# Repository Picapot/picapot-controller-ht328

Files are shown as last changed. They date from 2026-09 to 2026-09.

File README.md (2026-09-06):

# Picapot Irrigation Controller

This repository contains the latest firmware for the Picapot Irrigation Controller HT328.3.2.

The hardware design, user manual, 3D printable enclosure, and complete project documentation are freely available at:

https://www.picapot.com

## Build and Upload

A precompiled `.hex` file is available for direct upload to the microcontroller. If you don't need to change anything of the program, you can just upload the precompiled firmware.

### Compile from Source 

The code has been developed using the Arduino IDE and should be compiled using the GyverCore board package. You can add this board to the Arduino IDE by adding the following line to **Settings → Additional Boards Manager URLs**:

```text
https://alexgyver.github.io/package_GyverCore_index.json
```

**GyverCore board settings**

- B.O.D.: `2.7V [Default]`
- Bootloader: `Without bootloader [Warning!]`
- Clock: `External 16 MHz`
- Clock out: `Disable [Default]`
- Compiler version: `AVR-GCC v5.4 or 7.3 [Default]`
- Save EEPROM: `Enable`
- Initialization: `Enable [Default]`
- Serial: `Default Serial`
- System timer: `Enable [Default]`

### Upload to the Controller

The compiled `.hex` file can be uploaded to the microcontroller via port P1 using an AVR programmer and the [AVRDUDE](https://github.com/avrdudes/avrdude/releases) command-line tool.

The first command sets the correct fuses:

```console
avrdude -c avrispmkii -p atmega328p -B 100 -v -U lfuse:w:0xEF:m -U hfuse:w:0xC7:m -U efuse:w:0xFD:m
```

The second command uploads the program to flash memory:

```console
avrdude -c avrispmkii -p atmega328p -B 0.5 -v -U flash:w:picapot-controller-ht328.ino.hex:i
```

The programmer used in the commands above is the AVR ISP MKII (`avrispmkii`). If you are using a different programmer, update the programmer ID in the commands accordingly.

To run the commands as shown, AVRDUDE must be available in the system `PATH`, and the `.hex` file must be in the terminal's current working directory.

### First Run

During the first execution of the firmware, the controller scans the 1-Wire network to detect the internal DS18B20 temperature sensor and stores its address in EEPROM. **It is important that no external sensors are connected at this stage**; otherwise, the controller will not be able to distinguish between the internal and external sensors.

## Repository Contents

- **picapot-controller-ht328.ino** — Firmware source code
- **picapot-controller-ht328.ino.hex** — Precompiled firmware for 128×64 SPI OLED displays based on SSD1306 and SSD1309 controllers

## Dependencies

- **Wire (I²C)**  
  https://github.com/esp8266/Arduino/blob/master/libraries/Wire/Wire.h

- **OneWire**  
  https://github.com/PaulStoffregen/OneWire

- **Dusk2Dawn**  
  https://github.com/Picapot/Dusk2Dawn  
  (fork of https://github.com/dmkishi/Dusk2Dawn)

- **SSD1306Ascii**  
  https://github.com/Picapot/SSD1306Ascii  
  (fork of https://github.com/greiman/SSD1306Ascii)

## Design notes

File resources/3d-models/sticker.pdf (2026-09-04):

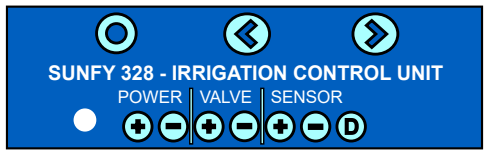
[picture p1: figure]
SUNFY 328 - IRRIGATION CONTROL UNIT; POWER; VALVE; SENSOR

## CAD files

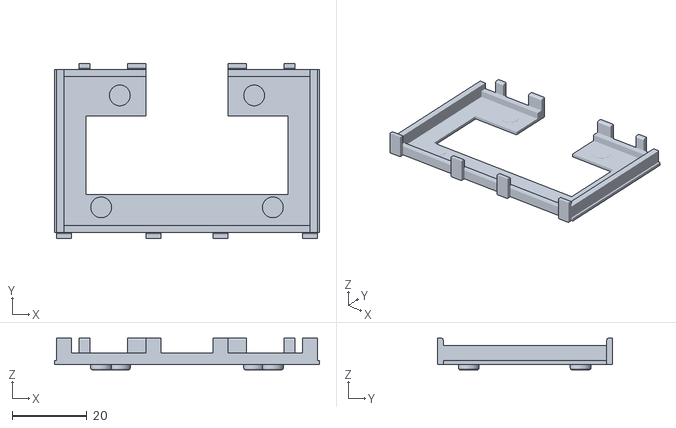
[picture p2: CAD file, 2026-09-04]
resources/3d-models/controller_screen_spacer.stl
71.0 x 46.8 x 8.50

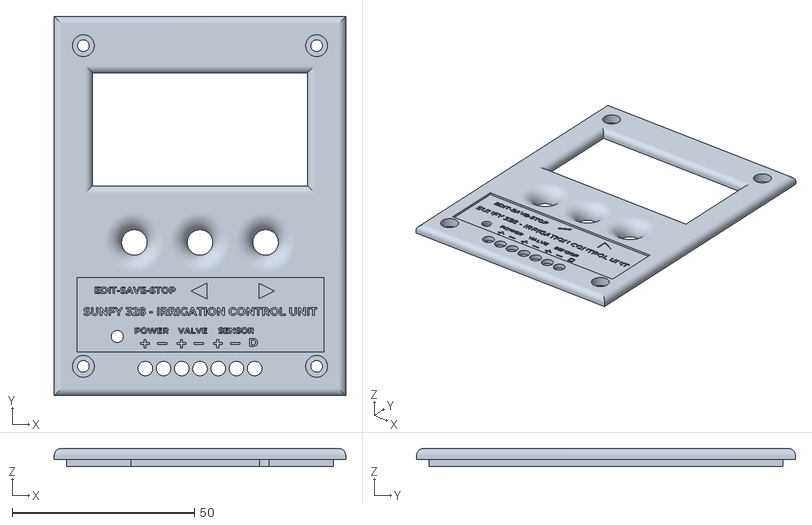
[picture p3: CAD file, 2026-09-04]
resources/3d-models/Picapot328-Cover.stl
80.0 x 104.0 x 5.00

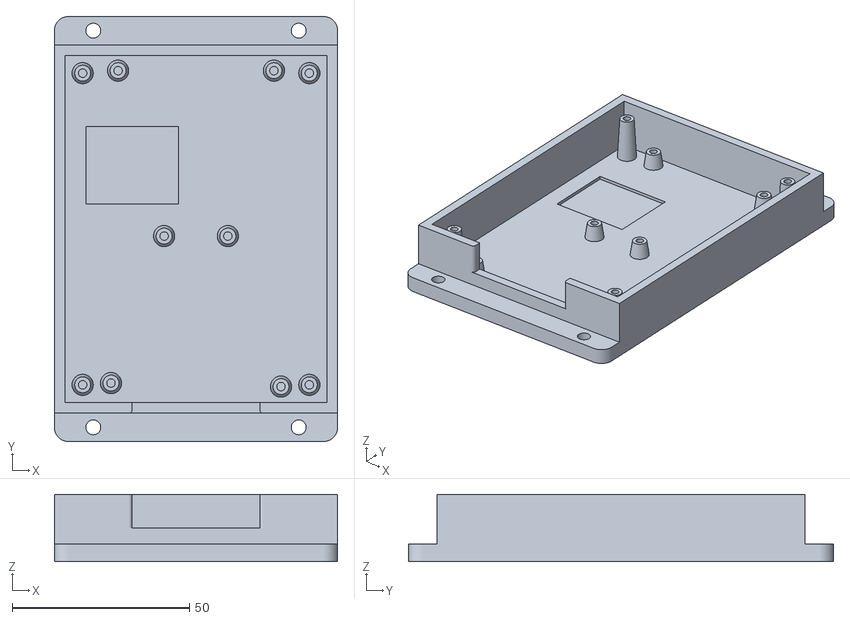
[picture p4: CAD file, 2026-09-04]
resources/3d-models/Picapot328-Base.stl
80.0 x 120.0 x 19.0

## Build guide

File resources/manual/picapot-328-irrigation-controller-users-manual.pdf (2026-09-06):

# Picapot 328 - Irrigation Controller

# User’s Manual

Version 3.2 rev. 5 Sep 2026

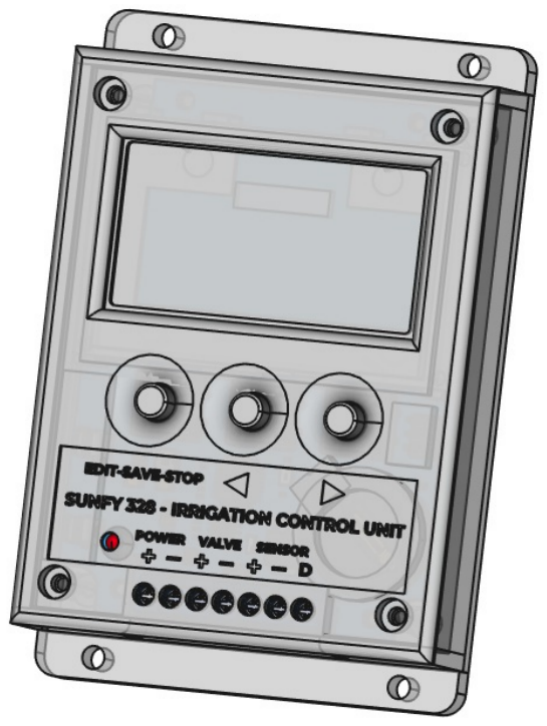
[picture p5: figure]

# Features

Picapot 328 can control one 12 V DC load (such as a solenoid valve, water pump, or relay) with a maximum continuous power consumption of 30 W. Real-time clock with optional automatic daylight saving, geolocation-based sunrise/sunset, fractional timezone support, leap year handling, calibration, and CR2032 battery backup.
Four watering modes: Fixed time, sunrise/sunset-automatic, sunrise/sunset-advanced, and fixed interval. Base duration can range from 15 seconds to 1 hour; seasonal compensation and Heat Boost can extend automatic watering.
Optional automatic seasonal adjustment of duration and watering interval.¹
Boost watering during heatwaves.
Frost protection: skip watering when the temperature is below 5 degrees to safeguard plants and the valve.
Manual watering with a timer for immediate valve control.
Skip watering based on soil moisture (requires an external soil moisture sensor).
Event history for the six most recent automatic waterings, manual waterings, and skipped waterings.
Automatic fallback to the internal temperature sensor if the selected external sensor is unavailable.
Low power consumption, ideal for off-grid systems.

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
# Installation

The control unit is not waterproof and must be enclosed in a waterproof box if installed outdoors.

The connector block has seven terminals. Connect them as described below.

Important - first start: power up the controller for the first time with only the internal DS18B20 connected. The controller stores the first detected sensor as the internal sensor. Connect the external sensor only after this initial registration has completed.

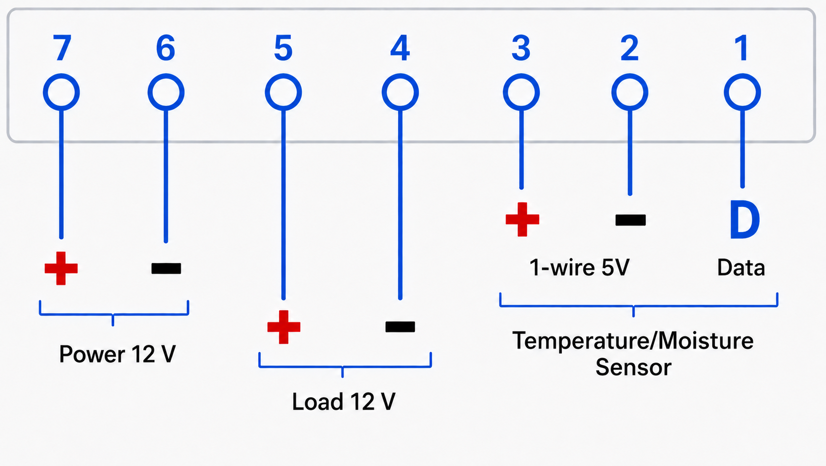
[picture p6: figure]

Picapot 328 terminal layout

Terminal | Description
7, 6 | Connect these two terminals to a 12 V power source. The power source must provide at least 0.25 A to supply the control unit and the sensor, in addition to the load current. The total current drawn by the system is limited by a 3 A fuse. The unit is protected against reverse polarity. 7) Positive (+12 V) 6) Negative
5, 4 | Connect these two terminals to the load, which must operate at the same voltage as the power source. Irrigation systems typically use a solenoid valve and/or a water pump. Solenoid valves are not polarity-sensitive, so the wires can be connected either way. Water pumps, however, must be connected with the correct polarity. The maximum continuous load power is 30 W at 12 V DC. Motor starting currents must also be considered. For higher-power loads, use an external relay rated for the load and its starting current, driven by the Picapot controller. 5) Positive (+12 V) 4) Negative

Picapot 328 - User's Manual - Version 3.2 rev. 5 Sep 2026 - www.picapot.com

Terminal | Description
3, 2, 1 | Connect these three terminals to the optional external sensor. The sensor can be a DS18B20, which provides temperature, or the Picapot PS100, which provides both temperature and soil moisture. The controller supports one internal sensor and one external sensor. 3) Positive (+5 V) 2) Negative 1) Data line

# Operation

The controller provides seven screens.

No. | Screen | Modes | Description
1 | Date/Time | View/Edit | The main screen shows the date, time, and sensor data.
2 | Schedule | View/Edit | Configuration of the waterings.
3 | Location | View/Edit | Unit geolocation, timezone, and daylight saving.
4 | Options | View/Edit | Remaining controller options.
5 | Events | View | History of automatic, manual, and skipped watering events.
6 | Sensor | View | Minimum and maximum temperatures and moisture levels of the day.
7 | Manual | View/Edit | Immediate watering.

Screens can be managed using three buttons:

Button | Position | Functions
1 | Left | Enter/exit edit mode when pressed for more than 2 seconds. In edit mode, move to the next edit cell. Stop watering when pressed for more than 2 seconds from the Date/Time screen.
2 | Middle | In view mode, move to the previous screen. In edit mode, decrease the edit cell by one unit.
3 | Right | In view mode, move to the next screen. In edit mode, increase the edit cell by one unit.

Use buttons 2 and 3 to navigate between screens.

To change values, enter edit mode by pressing and holding button 1 for more than 2 seconds. Then use buttons 2 and 3 to set the current field’s value. Press button 1 to move to the next field.

When all values have been set, press and hold button 1 for more than 2 seconds to exit edit mode.

The monitor is turned off after 60 seconds of inactivity. To wake it up, press one of the buttons. You can change the timeout from the Options screen.

The system will notify you when the RTC battery (CR2032) needs replacement.

When powered from USB through the ISP port at approximately 4.5 V, the DS1307 real-time clock (RTC) integrated circuit operates at the lower limit of its specified supply range, which may cause system instability and unexpected resets; therefore, powering the controller from a 12 V supply is always recommended, including during programming.

# Screen 1 - Date/Time

This is the main screen that appears after the system reboots or wakes from sleep mode.

This screen shows the following information:

Ord. | Name | Description
1 | Weekday
2 | Day
3 | Month | The transition from February to March on leap years is automatically managed.
4 | Year
5 | Hour | Time is shown in 24H format. When a Daylight Saving rule is selected on the Location screen, the displayed time is automatically adjusted according to that regional rule.
6 | Minute
7 | Second
8 | Temperature and Moisture | Temperature from the selected sensor. If a selected external sensor is unavailable, the internal DS18B20 is used as a fallback. Soil moisture is shown only when a valid external PS100 is available.
9 | RTC Battery | Estimated charge level of the RTC backup battery, shown as a percentage.
10 | Last Watering | Date, time, and duration of the last automatic watering.

During watering, this screen displays a blinking WATERING message and a timer showing the remaining time. You can stop watering at any time by pressing and holding button 1 for more than 2 seconds.

# Screen 2 - Schedule

This screen allows you to view and edit the watering settings.

Ord. | Name | Description
1 | Mode | The working mode of the watering. It can be one of the following options:
| | OFF: Scheduled watering disabled; manual watering remains available. FIXED TIME: The user can specify two exact times of the day for watering. Each watering can be disabled. AUTO DUSK2DAWN: Watering is performed 3 hours after dawn and 3 hours before dusk. The user can only change the duration; the rest of the screen settings are set to AUTO mode. ADVANCED DUSK2DAWN: Watering is performed after dawn and before dusk, with a time offset specified by the setting D2D. All the screen settings can be configured by the user. FIXED INTERVAL: Watering is performed at user- defined regular intervals, starting from a specified time. The interval can be 5, 10, 15, or 30 minutes, or 1, 2, 4, 8, 12, or 24 hours. An optional end time can be set for the same day; if the end time is OFF, watering runs continuously for 24 hours. If defined, the end time must be later than the start time on the same day.
2 | Duration | Base watering duration can be set between 15 seconds and 1 hour. Seasonal compensation and Heat Boost apply to automatic watering and can increase the effective duration.
3 | Season Compensation | The maximum increase applied to the alarm duration based on the current season. The longer the daylight period, the greater the increase. For example, if the duration is 5 minutes and the Season Compensation is set to 100%, the effective duration will be 5 minutes on the shortest day of the year and 10 minutes on the longest day of the year. OFF: No adjustment applied to the duration. AUTO: It is equal to 150% when mode = AUTO DUSK2DAWN. Alternatively, select a maximum increase between +50% and +400%.

Ord. | Name | Description
4 | Skip Watering Days | Number of days to skip between two waterings. OFF: Never skip watering days. AUTO: Uses the read-only Season value on the Location screen: • 0–24%: Every 3 days, at most one watering. • 25–44%: Every 2 days, at most one watering. • 45–62%: Daily; WT2 is eligible if today’s maximum temperature reaches 35°C (95°F), or no valid temperature is available. • 63–100%: Both WT1 and WT2 are eligible daily. Other watering skip conditions still apply. Alternatively, select a value between 1 and 6.
5 | Dusk to Dawn (D2D) | Time offset when Watering Mode is set to ADVANCED DUSK2DAWN. DAWN+1H DUSK-1H DAWN+2H DUSK-2H DAWN+3H DUSK-3H DAWN+4H DUSK-4H

Scheduled waterings do not start while settings are being edited or another watering is active. Missed starts are not queued.

# Screen 3 - Location

Use this screen to enter the controller’s geolocation.

Using this information, the controller can schedule watering at dawn and dusk, adjust the watering duration based on day length, and skip watering days when the option is set to AUTO.

Ord. | Name | Description
1 | Timezone | Timezone where the unit is located. It can be a value between -12 and +14 with 15-minute increments.
2 | Daylight Saving2 | Select the regional daylight saving rule. The controller automatically adds one hour during the applicable period. OFF: No daylight saving adjustment. EU: European Union rule. US: United States rule. AU: Australian rule. NZ: New Zealand rule.
3 | Latitude | Latitude of the unit. It can be a value between -90 and +90.
4 | Longitude | Longitude of the unit. It can be a value between -180 and +180.
5 | Season | Read-only seasonal level. The value ranges from 0% to 100%, indicating where the current daylight length falls between the shortest and longest days of the year at the configured location. It is used by seasonal compensation and automatic day-skipping rules.

# Screen 4 - Options

With this screen, you can view/edit the remaining options.

Ord. | Name | Description
1 | Sensor | Select the temperature and moisture source. INTERNAL: Internal DS18B20 temperature sensor. DS18B20: External DS18B20 temperature sensor. PS100: External Picapot temperature/moisture sensor. After connecting or disconnecting a sensor, enter and exit edit mode on the Options screen to trigger an immediate rescan of the 1-Wire network, or wait 30-40 seconds for the automatic rescan.
2 | Temperature Unit | The measurement unit of temperature. CELSIUS FAHRENHEIT
3 | Heat Boost | When the day’s maximum recorded temperature is equal to or greater than the specified value, the watering duration is increased by the specified percentage. OFF: Never adjust the watering duration due to high temperature. Alternatively, select a temperature between +30 and +55 Celsius (+86 and +131 Fahrenheit) and a percentage between 10% and 90%.
4 | Moisture Limit | When the moisture level is equal to or greater than the specified value, skip the watering. OFF: Never skip watering due to the moisture level. Alternatively, select a moisture value between 1% and 99%.
5 | Clock Calibration | The number of seconds of calibration applied every day to the clock. For example, if the clock loses one second every 24 hours, insert +1 to compensate for the loss. Select a value between -240 and +240 seconds.
6 | Screen Timeout | The screen turns off after a period of user inactivity defined by the specified timeout. Select a value between 1 and 60 minutes.

When an external sensor is selected but is not available, the controller falls back to the internal DS18B20 for temperature. Soil moisture display and moisture-based watering skips are disabled during fallback. After 10 consecutive failed readings (approximately 20 seconds), the controller clears the previous samples and rescans the sensor bus. Once operating with the internal fallback sensor, it checks once per minute for an available external sensor.

The internal sensor address is registered during the first start and retained separately in EEPROM, even after a settings reset. A replacement internal sensor with a different address is therefore not registered automatically.

# Screen 5 - Events

This screen displays the six most recent automatic waterings, manual waterings, and skipped watering attempts. Each entry contains the date, time, and either a duration or an event code.

Display | Meaning
Duration | Completed or started automatic watering.
M- followed by a duration | Manual watering.
Skip-D | Watering skipped by the Skip Watering Days setting.
Skip-M | Watering skipped because the moisture limit was reached.
Skip-I | Watering skipped by frost protection.
Skip-R | Repeated fixed-time or dusk/dawn trigger suppressed.
Skip-E | Second daily watering suppressed by the automatic seasonal/temperature rule.

If an automatic or manual watering is stopped from the Date/Time screen, its Events entry is updated with the actual elapsed duration. The Last Watering value shown on Screen 1 is updated only for automatic watering.

Only the most recent event is retained in battery-backed RTC memory and survives a normal controller restart. The other five entries are held in working memory and are cleared by a restart.

# Screen 6 - Sensor

This screen displays the current temperature and soil moisture level, along with the minimum and maximum values recorded for the current day. Moisture values are available only from a valid external PS100. Daily minimum and maximum values are also reset when the controller restarts.

# Screen 7 - Manual

With this screen, you can manually open the valve for the specified duration.

Press and hold the LEFT button for more than 2 seconds to enter edit mode. Select the desired watering duration, then press and hold the LEFT button again for more than 2 seconds to start watering.

You can stop watering by pressing and holding the LEFT button on the Date/Time screen for more than 2 seconds.

Ord. | Name | Description
1 | Duration | Watering duration can be set to a value from 15 seconds to 1 hour.

Manual watering is added to the Events screen. The Last Watering value on the Date/Time screen continues to show the last automatic watering. Manual watering does not affect the Skip Watering Days function, which counts days from the last automatic watering.

Manual duration is not increased by seasonal compensation or Heat Boost. Manual watering also bypasses automatic frost and moisture skips.

# Settings Backup and Recovery

Current settings, watering state, the last automatic watering, and the most recent event are stored in the battery-backed RAM of the RTC. Routine watering activity and event updates do not write to the microcontroller EEPROM.

An EEPROM backup snapshot is refreshed when edit mode is exited from the Schedule, Location, or Options screen. Editing only the date and time does not update this EEPROM backup.

If the RTC memory becomes invalid (for example, due to an RTC battery replacement) and a valid EEPROM backup is available, the standard firmware restores that backup automatically and restarts. The date and time must then be checked and set again before relying on the watering schedule. If no valid backup is available, default settings are loaded.

The registered address of the internal temperature sensor is stored in a separate EEPROM area. It is not erased by a normal settings reset, allowing the controller to distinguish the internal and external sensors after an RTC battery failure.

# User Assessment Disclaimer

Users must assess the suitability of the sensor and select irrigation settings according to their installation, plants, soil, water, and environmental conditions.

Fabrizio Ranieri reserves the right to make changes without further notice to any products described here. Fabrizio Ranieri makes no warranty, representation, or guarantee regarding suitability for a particular purpose and assumes no liability arising from the application or use of any product or circuit, including special, consequential, or incidental damages. Typical parameters can vary between applications and over time; the customer’s technical experts must validate all operating parameters for each application. No license is conveyed under Fabrizio Ranieri’s patent rights or the rights of others.

Fabrizio Ranieri products are not designed, intended, or authorized for life-support, life-sustaining, or other applications in which product failure could result in personal injury, death, or harm to animals. A buyer using the products in such an unintended or unauthorized application agrees to indemnify and hold Fabrizio Ranieri and its officers, employees, subsidiaries, affiliates, and distributors harmless against related claims, costs, damages, expenses, and reasonable legal fees, including claims alleging negligence in product design or manufacture.

Fabrizio Ranieri is not responsible for damage including loss or death of plants, equipment malfunction, or crop failure resulting from product use or misuse. The user assumes all risks associated with application, integration, and operation. Fabrizio Ranieri disclaims liability for direct, indirect, incidental, or consequential damages, including monetary loss, arising from use of the product.

The season is calculated as a function of the length of the day. This works well in most countries, but not those very close to the equator or the poles.↩

The RTC stores standard time. The selected regional rule is applied to the displayed time and to watering calculations. Select OFF where daylight saving is not observed or where none of the available regional rules applies.↩

1.

2.

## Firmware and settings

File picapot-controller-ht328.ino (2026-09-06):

//board=GyverCore:avr:nano:bod=bod_2_7,boot=no,clock=external_16,co=disabled,compiler_version=avrgcc5,es=disabled ,init=enable,serial=default,timers=yes_millis

//   <!--------------------------------------------------------------------------------------------->
//   <!--    PICAPOT 328 IRRIGATION CONTROLLER                                                    -->
//   <!--    Copyright (c) Fabrizio Ranieri                                                       -->
//   <!--    Hardware and instructions at www.picapot.com                                         -->
//   <!--                                                                                         -->
//   <!--    Licensed under the Open Community License v1.1 with the General Attribution          -->
//   <!--    add-on v1 (OCL v1.1 + GAtt v1). See the LICENSE file for the applicable terms.       -->
//   <!--                                                                                         -->
//   <!--    This software is provided without warranty of any kind, to the maximum extent        -->
//   <!--    permitted by applicable law.                                                         -->
//   <!--------------------------------------------------------------------------------------------->
#include <avr/wdt.h>              // watchdog library https://www.nongnu.org/avr-libc/user-manual/group__avr__watchdog.html
#include <avr/sleep.h>            // sleep mode library https://www.nongnu.org/avr-libc/user-manual/group__avr__sleep.html
#include <avr/power.h>            // power control library https://www.nongnu.org/avr-libc/user-manual/group__avr__power.html 
#include <Wire.h>                 // I2C protocol library https://github.com/esp8266/Arduino/blob/master/libraries/Wire/Wire.h
#include <OneWire.h>              // 1-Wire protocol library https://github.com/PaulStoffregen/OneWire
#include <EEPROM.h>               // EEPROM read/write library https://github.com/arduino/ArduinoCore-avr/tree/master/libraries/EEPROM
#include <Dusk2Dawn.h>            // daily dusk and dawn library https://github.com/Picapot/Dusk2Dawn fork of https://github.com/dmkishi/Dusk2Dawn 
#include "SSD1306AsciiSpi.h"      // library for the screen  https://github.com/Picapot/SSD1306Ascii fork of https://github.com/greiman/SSD1306Ascii

// USER SETTINGS ////////////////////////////////////////////////////////
#define SCREEN_CONTRAST 32            // Range: 0–255
#define SKIP_ICE 5                    // Skip watering when temperature is below this limit (°C); 0 = disabled
#define SKIPDAYS_WINTER_PERC 25       // Auto mode: below this %, skip 2 days between waterings and use max 1 watering/day
#define SKIPDAYS_EARLY_SPRING_PERC 45 // Auto mode: below this %, skip 1 day between waterings and use max 1 watering/day
#define SKIPDAYS_LATE_SPRING_PERC 63  // Auto mode: below this %, water daily; in the 45-66% range WT2 runs when today's max temperature is >= the threshold or the sensor is unavailable; from 67%, water twice per day
#define DOUBLE_WATERING_TEMP 35       // Celsius; in the 45-66% season range skip WT2 only when a valid maximum temperature for today is below this value
#define DEFAULT_LONGITUDE +14         // Default longitude after reset (Malta); reset by restarting without the CR2032 backup battery
#define DEFAULT_LATITUDE +35          // Default latitude after reset (Malta)
#define DEFAULT_TIMEZONE +4           // Default timezone after reset; expressed in 15-minute increments; +4 = +01:00 (e.g. Malta); Venezuela (-04:30) = -18
#define DST_DISABLED 0
#define DST_EUROPE 1
#define DST_USA 2
#define DST_AUSTRALIA 3
#define DST_NEW_ZEALAND 4
#define DEFAULT_DAYLIGHT_SAVING DST_EUROPE // Default daylight saving mode after reset
#define AUTORESTORE 1                 // Automatically restore system after memory failure if backup is available; 0 = no, 1 = yes. Date and time must be adjusted, otherwise the watering schedule will be incorrect.

// SYSTEM SETTINGS ////////////////////////////////////////////////////////
#define SCREEN_TYPE &Adafruit128x64   // Use &SH1106_128x64 for SH1106 displays and &Adafruit128x64 for SSD1306/SSD1309 displays
#define CLOCK_ADDRESS 0x68            // I2C address of the DS1307 real-time clock
#define BLINK_FREQ 200                // Blinking interval in ms for edit mode
#define EDIT_FREQ 70                  // Button processing interval; controls auto increment/decrement speed when buttons 2 and 3 are held in edit mode
#define DEBOUNCE_DELAY 25             // Button debouncing delay in ms
#define SYSTEM_DELAY 5                // Delay in ms after each wire bulk read/write operation
#define SOIL_SENSOR_MIN 1             // Lower bound offset for the soil sensor value
#define SOIL_SENSOR_MAX 65535         // Upper bound offset for the soil sensor value
#define SOIL_SENSOR_INVERTED 0        // 0 = low value means low moisture, 1 = low value means high moisture

// PINS ////////////////////////////////////////////////////////
#define PIN_INT0 2                   // Interrupt-0 connected to the RTC 1Hz square wave output
#define PIN_LED 0                    // Red LED
#define PIN_ONE_WIRE 7               // I/O pin for the humidity sensor (1-Wire protocol)
#define PIN_SPI_CS  9                // SPI screen CS pin
#define PIN_SPI_RST A1               // SPI screen RST pin
#define PIN_SPI_DC  10               // SPI screen DC pin    
#define PIN_BTN1 1                   // Button 1 (left)
#define PIN_BTN2 4                   // Button 2 (middle)
#define PIN_BTN3 3                   // Button 3 (right)
#define PIN_OUT 5                    // MOSFET gate (controls the solenoid valve)    
#define PIN_BAT_CHECK A2             // Analog input for battery voltage measurement
#define PIN_DS18B20_VC 8             // Temperature sensor power supply


//MACROS ////////////////////////////////////////////////////////
#define SWAP(a, b) { int16_t t = a; a = b; b = t; }

//FONTS ////////////////////////////////////////////////////////
// Free Font LCD5x7 revisited using GLCD Font Creator https://www.mikroe.com/glcd-font-creator. 
// Some characters have been changed to icons:
// '=TOP ARROW  ,=BOTTOM ARROW  *=WATER DROP  @=DEGREE CELSIUS  $=DEGREE FAHRENHEIT
// "=BATTERY LEFT SIDE  ;=RIGHT SIDE  _=EMPTY SEGMENT  `=FULL SEGMENT
// Some chars are reserved and used as text formatting elements:
// &=PLACEHOLDER  [=1x PIXEL SPACE  ]=4x PIXEL SPACE  ^=LINEFEED
GLCDFONTDECL(lcd5x7m) = {
  0x00, 0x00, 0x05, 0x07, 0x20, 0x41, // 0, 0, width, height, first char, char count(65)
  0x00, 0x00, 0x00, 0x00, 0x00,   0x00, 0x00, 0x4F, 0x00, 0x00,   0x00, 0x00, 0x00, 0x3E, 0x3E,   0x04, 0x04, 0x04, 0x04, 0x04,   0x02, 0x05, 0x7E, 0x14, 0x04, // SPACE ! " # $
  0x23, 0x13, 0x08, 0x64, 0x62,   0x36, 0x49, 0x55, 0x22, 0x50,   0x0C, 0x06, 0x7F, 0x06, 0x0C,   0x00, 0x1C, 0x22, 0x41, 0x00,   0x00, 0x41, 0x22, 0x1C, 0x00, // % & ' ( )
  0x38, 0x46, 0x47, 0x5C, 0x38,   0x08, 0x08, 0x3E, 0x08, 0x08,   0x18, 0x30, 0x7F, 0x30, 0x18,   0x08, 0x08, 0x08, 0x08, 0x08,   0x00, 0x60, 0x60, 0x00, 0x00, // * + , - .
  0x20, 0x10, 0x08, 0x04, 0x02,   0x3E, 0x51, 0x49, 0x45, 0x3E,   0x00, 0x42, 0x7F, 0x40, 0x00,   0x42, 0x61, 0x51, 0x49, 0x46,   0x21, 0x41, 0x45, 0x4B, 0x31, // / 0 1 2 3
  0x18, 0x14, 0x12, 0x7F, 0x10,   0x27, 0x45, 0x45, 0x45, 0x39,   0x3C, 0x4A, 0x49, 0x49, 0x30,   0x01, 0x71, 0x09, 0x05, 0x03,   0x36, 0x49, 0x49, 0x49, 0x36, // 4 5 6 7 8
  0x06, 0x49, 0x49, 0x29, 0x1E,   0x00, 0x00, 0x24, 0x00, 0x00,   0x3E, 0x00, 0x00, 0x00, 0x00,   0x08, 0x14, 0x22, 0x41, 0x00,   0x00, 0x14, 0x14, 0x14, 0x00, // 9 : ; < =
  0x00, 0x41, 0x22, 0x14, 0x08,   0x02, 0x01, 0x51, 0x09, 0x06,   0x02, 0x05, 0x3A, 0x44, 0x44,   0x7E, 0x11, 0x11, 0x11, 0x7E,   0x7F, 0x49, 0x49, 0x49, 0x36, // > ? @ A B
  0x3E, 0x41, 0x41, 0x41, 0x22,   0x7F, 0x41, 0x41, 0x22, 0x1C,   0x7F, 0x49, 0x49, 0x49, 0x41,   0x7F, 0x09, 0x09, 0x09, 0x01,   0x3E, 0x41, 0x49, 0x49, 0x7A, // C D E F G
  0x7F, 0x08, 0x08, 0x08, 0x7F,   0x00, 0x41, 0x7F, 0x41, 0x00,   0x20, 0x40, 0x41, 0x3F, 0x01,   0x7F, 0x08, 0x14, 0x22, 0x41,   0x7F, 0x40, 0x40, 0x40, 0x40, // H I J K L
  0x7F, 0x02, 0x0C, 0x02, 0x7F,   0x7F, 0x04, 0x08, 0x10, 0x7F,   0x3E, 0x41, 0x41, 0x41, 0x3E,   0x7F, 0x09, 0x09, 0x09, 0x06,   0x3E, 0x41, 0x51, 0x21, 0x5E, // M N O P Q
  0x7F, 0x09, 0x19, 0x29, 0x46,   0x46, 0x49, 0x49, 0x49, 0x31,   0x01, 0x01, 0x7F, 0x01, 0x01,   0x3F, 0x40, 0x40, 0x40, 0x3F,   0x1F, 0x20, 0x40, 0x20, 0x1F, // R S T U V
  0x3F, 0x40, 0x30, 0x40, 0x3F,   0x63, 0x14, 0x08, 0x14, 0x63,   0x07, 0x08, 0x70, 0x08, 0x07,   0x61, 0x51, 0x49, 0x45, 0x43,   0x00, 0x7F, 0x41, 0x41, 0x00, // W X Y Z [
  0x02, 0x04, 0x08, 0x10, 0x20,   0x00, 0x41, 0x41, 0x7F, 0x00,   0x04, 0x02, 0x01, 0x02, 0x04,   0x22, 0x22, 0x22, 0x22, 0x22,   0x3E, 0x3E, 0x3E, 0x3E, 0x3E  // \ ] ^ _ `

};


//Time font
GLCDFONTDECL(lucida10x14) = {
0x00, 0x00, 0x0B, 0x10, 0x2F, 0x0C, // 0, 0, width (11), height (16), first char, char count(12)
0x00, 0x00, 0x00, 0x00, 0x00, 0x00, 0x00, 0x00, 0x00, 0x00, 0x00, 0x00, 0x00, 0x00, 0x00, 0x00, 0x00, 0x00, 0x00, 0x00, 0x00, 0x00,  // Code for char SPACE
0xF8, 0xFE, 0x06, 0x03, 0x83, 0xC3, 0x63, 0x33, 0x1E, 0xFE, 0xF8, 0x07, 0x1F, 0x1E, 0x33, 0x31, 0x30, 0x30, 0x30, 0x18, 0x1F, 0x07,  //  Code for char 0  
0x00, 0x00, 0x0C, 0x0C, 0x0E, 0xFF, 0xFF, 0x00, 0x00, 0x00, 0x00, 0x00, 0x00, 0x30, 0x30, 0x30, 0x3F, 0x3F, 0x30, 0x30, 0x30, 0x00,  //  Code for char 1  
0x1C, 0x1E, 0x07, 0x03, 0x03, 0x83, 0xC3, 0xE3, 0x77, 0x3E, 0x1C, 0x30, 0x38, 0x3C, 0x3E, 0x37, 0x33, 0x31, 0x30, 0x30, 0x30, 0x30,  //  Code for char 2  
0x0C, 0x0E, 0x07, 0xC3, 0xC3, 0xC3, 0xC3, 0xC3, 0xE7, 0x7E, 0x3C, 0x0C, 0x1C, 0x38, 0x30, 0x30, 0x30, 0x30, 0x30, 0x39, 0x1F, 0x0E,  //  Code for char 3  
0xC0, 0xE0, 0x70, 0x38, 0x1C, 0x0E, 0x07, 0xFF, 0xFF, 0x00, 0x00, 0x03, 0x03, 0x03, 0x03, 0x03, 0x03, 0x03, 0x3F, 0x3F, 0x03, 0x03,  //  Code for char 4  
0x3F, 0x7F, 0x63, 0x63, 0x63, 0x63, 0x63, 0x63, 0xE3, 0xC3, 0x83, 0x0C, 0x1C, 0x38, 0x30, 0x30, 0x30, 0x30, 0x30, 0x38, 0x1F, 0x0F,  //  Code for char 5  
0xC0, 0xF0, 0xF8, 0xDC, 0xCE, 0xC7, 0xC3, 0xC3, 0xC3, 0x80, 0x00, 0x0F, 0x1F, 0x39, 0x30, 0x30, 0x30, 0x30, 0x30, 0x39, 0x1F, 0x0F,  //  Code for char 6  
0x03, 0x03, 0x03, 0x03, 0x03, 0x03, 0xC3, 0xF3, 0x3F, 0x0F, 0x03, 0x00, 0x00, 0x00, 0x30, 0x3C, 0x0F, 0x03, 0x00, 0x00, 0x00, 0x00,  //  Code for char 7  
0x00, 0xBC, 0xFE, 0xE7, 0xC3, 0xC3, 0xC3, 0xE7, 0xFE, 0xBC, 0x00, 0x0F, 0x1F, 0x39, 0x30, 0x30, 0x30, 0x30, 0x30, 0x39, 0x1F, 0x0F,  //  Code for char 8  
0x3C, 0x7E, 0xE7, 0xC3, 0xC3, 0xC3, 0xC3, 0xC3, 0xE7, 0xFE, 0xFC, 0x00, 0x00, 0x30, 0x30, 0x30, 0x38, 0x1C, 0x0E, 0x07, 0x03, 0x00,  //  Code for char 9  
0x00, 0x00, 0x00, 0x70, 0x70, 0x70, 0x00, 0x00, 0x00, 0x00, 0x00, 0x00, 0x00, 0x00, 0x1C, 0x1C, 0x1C, 0x00, 0x00, 0x00, 0x00, 0x00  //  Code for char :     

};
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
void loop()
{
  long i = 0;
  resetWdt(); // restart the 8 seconds counter of the watchdog
  byte _intBTN = intBTN; // copy volatile flags to local variables
  byte _intRTC = intRTC;
  if (_intBTN > 0) { // clear volatile flag
    intBTN = 0;
  }
  if (_intRTC > 0) { // clear volatile flag
    intRTC = 0;
  }
  if (_intBTN > 0) { // if a button is pressed, wake up from screen sleep mode,
    sleepCt = 0;
    if (screenSleep == true) { // only if the system is actually sleeping
      SwitchOnScreen();
      skipButtonProcess = true;
    }
  }
  if ((_intRTC > 0) || (_intBTN > 0) || (editMode == true)) { //one of the two interrupts has been triggered, or edit mode is ON
    dtm = GetDateTime(); // DS1307 keeps datetime without daylight saving which is added when printing at screen

    isSummerTime=IsSummerTime(dtm);
    if (isSummerTime)
    {
      dtm_ds = Add1Hour(dtm); 
    } else {
      dtm_ds = dtm;
    }
  }
  if (isFirstLoop)
  {
      CalculateNextWatering();
      isFirstLoop=false;
  }

  if ((_intRTC > 0) || (_intBTN > 0)) { // one of the two interrupts has been triggered
    if (_intRTC > 0) { // the interrupt comes from the 1Hz square wave
      Blink(1, 0); // blink the led for 1 millisecond

      if ((dtm_ds.second%2)==1) //every two seconds check the sensor
      {
        int tmptmp=0;
        if (sensorType > 0 && extSensorIdx == intSensorIdx && dtm_ds.second == 1) {
          getTempSensorAddress(); // retry the external sensor once per minute while using the internal fallback
        }
        getTemperatureAndHumidity_DS18B20(temperatureSensorAddress[sensorType == 0 ? intSensorIdx : extSensorIdx]);            

        //average of temperature
        if (sensorErr==0)
        {
          for (byte x = 9; x > 0; x--) {
            temperatureSample[x] = temperatureSample[x - 1];
          }
          temperatureSample[0] = temperatureSensorValueRaw;
          i = 0;
          for (byte x = 0; x < sampleCt1; x++) {
            i += temperatureSample[x];
          }
          temperatureSensorValue = i / sampleCt1;
          if (dateDiff(minTempDateTime, dtm_ds) != 0 || temperatureSensorValue < minTempValue) {
            minTempDateTime = dtm_ds;
            minTempValue = temperatureSensorValue;
          }
          if (dateDiff(maxTempDateTime, dtm_ds) != 0 || temperatureSensorValue > maxTempValue) {
            maxTempDateTime = dtm_ds;
            maxTempValue = temperatureSensorValue;
          }
          if (sampleCt1<10)
          {
            sampleCt1++;
          }
        }



        if (sensorErr==0)
        {
          //humidity
          i = soilSensorValueRaw;
          if (i>0)
          {
            if (i < SOIL_SENSOR_MIN)
            {
              i = SOIL_SENSOR_MIN;
            }
            i = i - SOIL_SENSOR_MIN;
            if (i > (SOIL_SENSOR_MAX - SOIL_SENSOR_MIN))
            {
              i = SOIL_SENSOR_MAX - SOIL_SENSOR_MIN;
            }
            for (byte x = 9; x > 0; x-- ) {
              soilMoistureSample[x] = soilMoistureSample[x - 1];
            }
            soilMoistureSample[0] = i;
            i = 0;
            for (byte x = 0; x < sampleCt2; x++ ) {
              i = i + soilMoistureSample[x];
            }
            soilSensorValue = i / sampleCt2;   
            //record the minimum and maximum of the day
            if (dateDiff(minHumDateTime, dtm_ds) != 0 || soilSensorValue < minHumValue) {
              minHumDateTime = dtm_ds;
              minHumValue = soilSensorValue;
            }
            if (dateDiff(maxHumDateTime, dtm_ds) != 0 || soilSensorValue > maxHumValue) {
              maxHumDateTime = dtm_ds;
              maxHumValue = soilSensorValue;
            }  
            if (sampleCt2<10)
            {
              sampleCt2++;
            }   
          }
          
        }

        if (sensorErr == 10)
        {
          memset(temperatureSample, 0, sizeof(temperatureSample));
          memset(soilMoistureSample, 0, sizeof(soilMoistureSample));

          temperatureSensorValue = 250;
          soilSensorValue = 0;
          soilSensorValueRaw = 0;

          sampleCt1 = 1;
          sampleCt2 = 1;

          getTempSensorAddress();
        }
      }


      
      //  every six minutes apply clock calibration using the clock calibration array (more info from the function CreateCalibrationMatrix).
      if (((dtm.hour * 60 + dtm.minute) % 6) == 0 && dtm.second == 20) { // apply the calibration after a few seconds to avoid concurrency with waterings
        if ((ReadCalibrationBit((dtm.hour * 60 + dtm.minute) / 6) == true) && (clockCalibration != 0)) {
          if (screenSleep == true) {
            SwitchOnScreen();
            delay(SYSTEM_DELAY);
          }
          sleepCt = (screenSaver*60) - 8; //switch ON the screen for 8 seconds during calibration
          Screen.clear();
          if (clockCalibration < 0) {
            dtm.second = 19;
          } else {
            dtm.second = 21;
          }
          SetDateTime(dtm);
          printMsg(13); //CALIB
          resetWdt();
          delay(3000);
        }
        resetWdt();
        // every six minutes save the day min/max temperature to the clock memory and recalculate adjWaterResult
        CalculateNextWatering();
        SaveSettings(false);
        // refresh battery level
        batteryLevel = getBatteryLevel();
        //delete skip message
        if (activeScreen==1 & AlmTrig == 0)
        {
            printMsg(23);
        }
      } 
      else
      {
        if (activeScreen == 6)
        {
          batteryLevel = getBatteryLevel();
        }
      }        // end of clock calibration
    } // end of 1Hz square wave processing

    if (AlmTrig == 0 && screenSleep == false) { // if no watering is triggered, increase the counter for the sleep mode
      sleepCt++;
    }
    CheckWaterings(); // check if there is a watering to switch ON
    if (editMode == false) { // screen is refreshed every interrupt if not in edit mode
      refreshNow = true;
    }
  } // end of interrupts processing

  SwitchOffWatering(); // check the watering timeout every loop, even if RTC interrupts stop
  
  if (sleepCt > (screenSaver*60)) { // Switch off the screen after n seconds of inactivity
    screenSleep = true;
    sleepCt = 0;
    editMode = false;
    blinkPos = 0;
    pressCt = 0;
    activeScreen = 1;
    Screen.clear();
    Screen.ssd1306WriteCmd(SSD1306_DISPLAYOFF);
    Screen.ssd1306WriteCmd(SH1106_SET_PUMP_MODE);
    Screen.ssd1306WriteCmd(SH1106_PUMP_OFF);
  }
  if (screenSleep == false) { // buttons are monitored every loop (don't process buttons during sleep mode and don't process buttons that woke up from sleep mode)
    MonitorButtons();
    if ((millis() - ms) > EDIT_FREQ) { // buttons are processed only every 70 ms (to have a proper input increase/decrease speed, when they are kept pressed)
      ms = millis();
      ProcessButtons();
      if ((editMode == true))  { // screen is refreshed only when necessary
        refreshNow = true;
      }
    }
    if ((millis() - lastBlink) > BLINK_FREQ) { // This to have the blink effect in edit mode (200 ms)
      blinkStatus = !blinkStatus;
      lastBlink = millis();
      if ((editMode == true) || ((AlmTrig != 0) && activeScreen == 1)) { // screen is refreshed only when necessary
        refreshNow = true;
      }
    }
  }
  if (screenSleep == false)
  {
    if (refreshNow == true) { // screen is not refreshed every loop but only when necessary
      PrintScreen(activeScreen);
      refreshNow = false;
    }
  }

  if (screenSleep == true) { // unless the screen is active, go to sleep mode, till the next 1Hz (1 second) square wave signal
    set_sleep_mode(SLEEP_MODE_PWR_DOWN);
    sleep_enable();
    noInterrupts ();
    power_all_disable();
    sleep_bod_disable();
    interrupts ();
    sleep_cpu();
    sleep_disable(); //wake up here
    power_all_enable();

  }

  delay(2);
} // End of loop
// ========================================================================================




void ClockInterrupt() { // 1Hz square wave signal from the clock
  intRTC++;
}


ISR (PCINT2_vect) { // buttons pin status change
  intBTN++;
}
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

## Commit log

2026-09-04 Initial commit
    Adding firmware and resources
    [Picapot328-Base.stl, Picapot328-Cover.stl, controller_screen_spacer.stl]
2026-09-06 fix: handle edge cases in watering schedule
    - Check watering timeout independently of RTC interrupts and close the valve before saving settings.
    - Fix duration and log display overflows; clamp seasonal compensation to 0–100%.
    - Reject incomplete RTC reads while allowing temporary dates during editing.
    - Recover from out-of-range RTC fields by saving watering mode as OFF and resetting the clock to 2000-01-01.
    - Reject incomplete settings reads before processing the buffer.
    - Prevent fixed alarms from repeating the last automatic watering in the same local date and minute, reducing duplicates during the autumn clock change.
    - Fix negative temperature formatting on the main and sensor screens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
    [picapot-controller-ht328.ino]
